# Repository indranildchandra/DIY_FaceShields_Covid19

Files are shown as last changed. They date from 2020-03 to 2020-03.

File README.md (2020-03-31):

# 10000 Face Shields For #COVID19 In India
* [Campaign page](https://www.ketto.org/donate-face-shields-to-covid-19-warriors-in-india?payment=form)

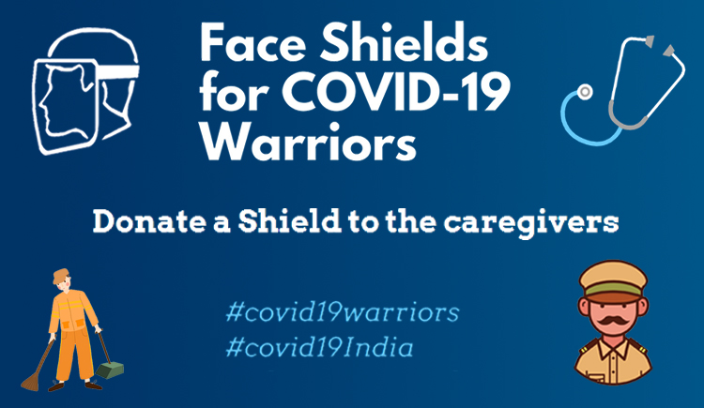
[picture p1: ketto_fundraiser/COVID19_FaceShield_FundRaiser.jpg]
Fundraiser


## Shield Images
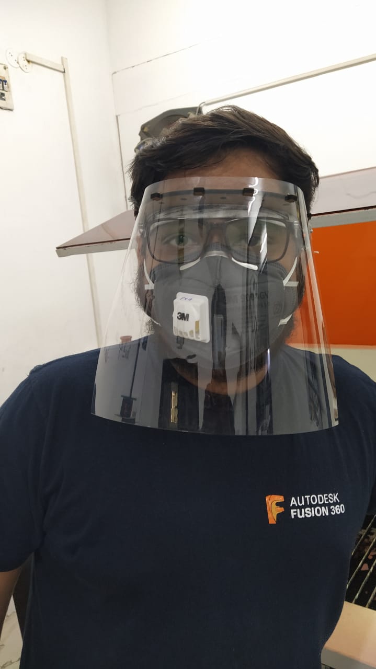
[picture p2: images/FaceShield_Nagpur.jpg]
Face Shield

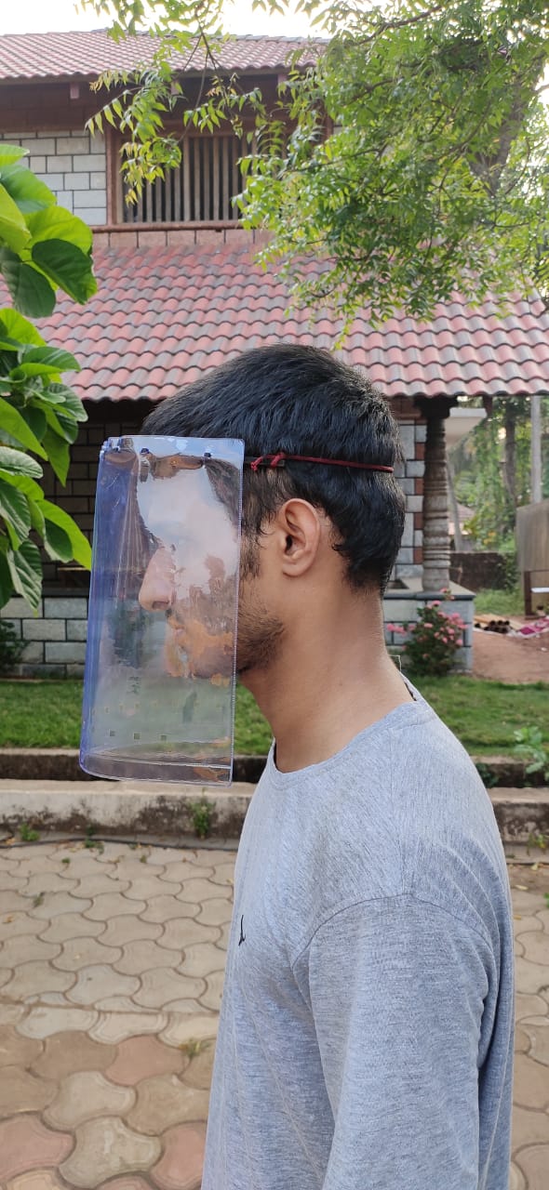
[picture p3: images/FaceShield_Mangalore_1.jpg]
Face Shield

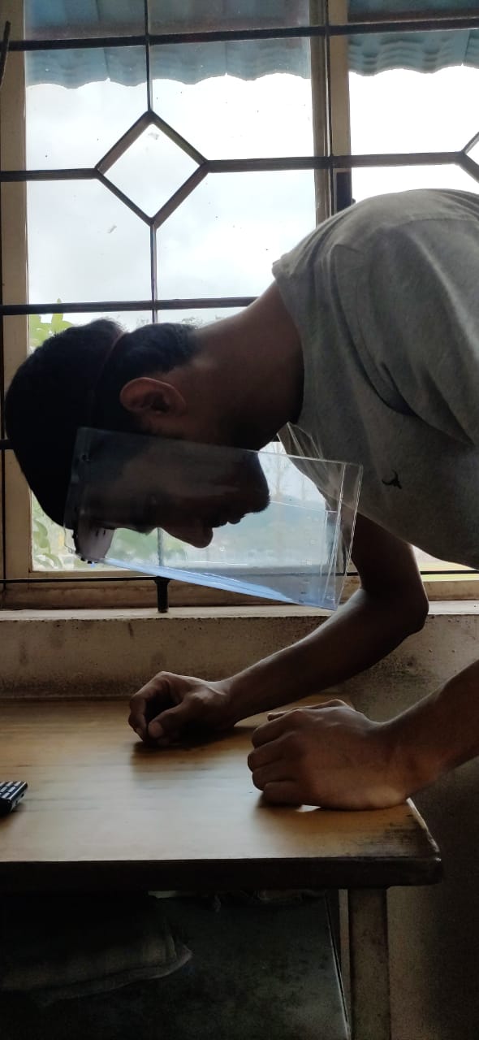
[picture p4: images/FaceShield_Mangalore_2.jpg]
Face Shield


## Design Credits
[Designs released by Makers Asylum Mumbai were re-used](https://github.com/MakersAsylumIndia/Covid-19)

License
-------
[CERN Open Hardware Licence Version 2 - Strongly Reciprocal]

[CERN Open Hardware Licence Version 2 - Strongly Reciprocal]:https://www.ohwr.org/project/cernohl/wikis/uploads/002d0b7d5066e6b3829168730237bddb/cern_ohl_s_v2.txt

[CERN OHL S v2 FAQ]: https://ohwr.org/project/cernohl/wikis/faq

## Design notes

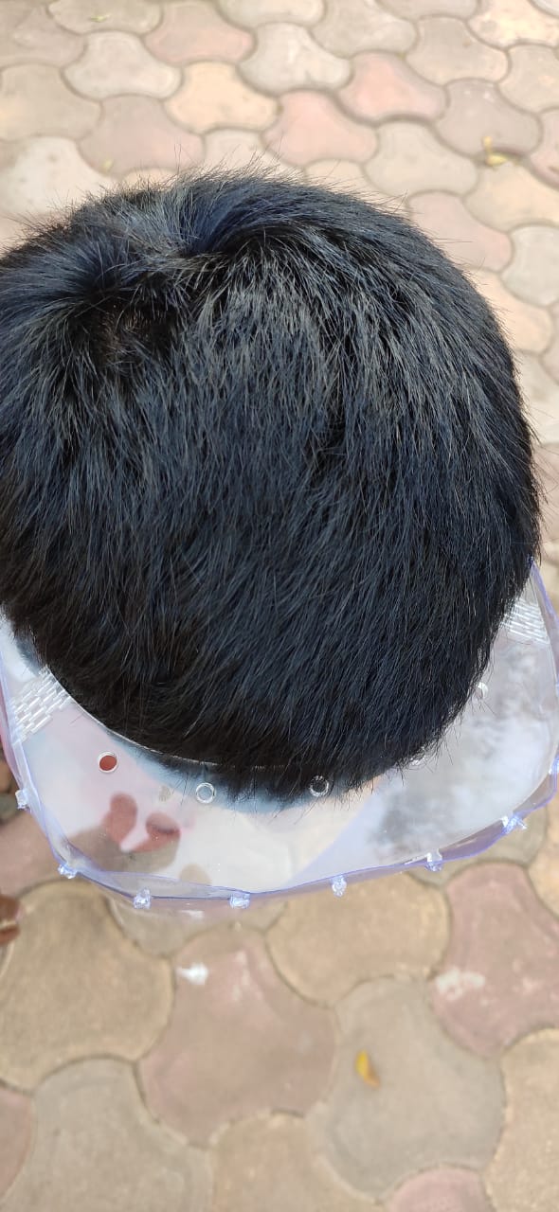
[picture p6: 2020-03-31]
images/FaceShield_Mangalore_4.jpg

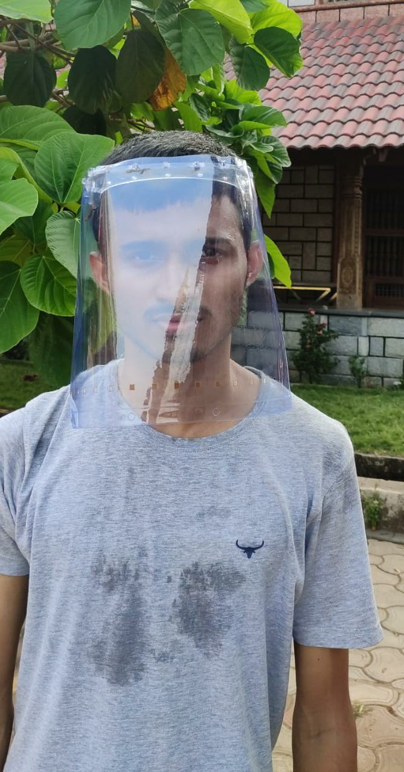
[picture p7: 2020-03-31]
images/FaceShield_Mangalore_3.jpg

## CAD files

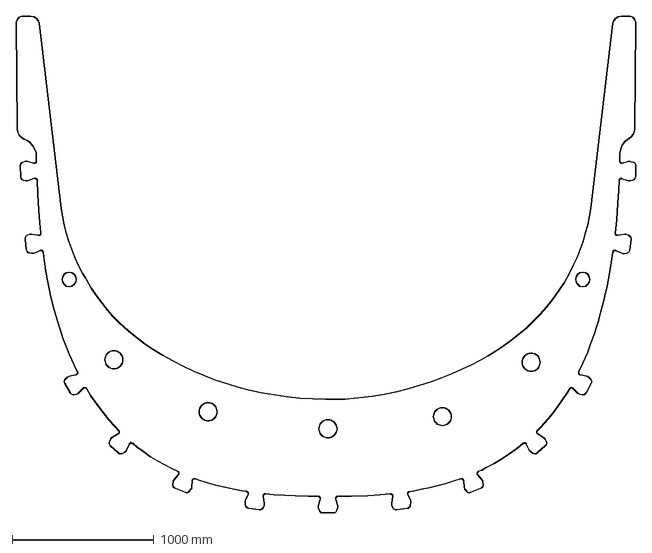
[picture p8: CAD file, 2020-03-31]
designs/face_shield_design.DXF
4367.9 x 3498.0 mm

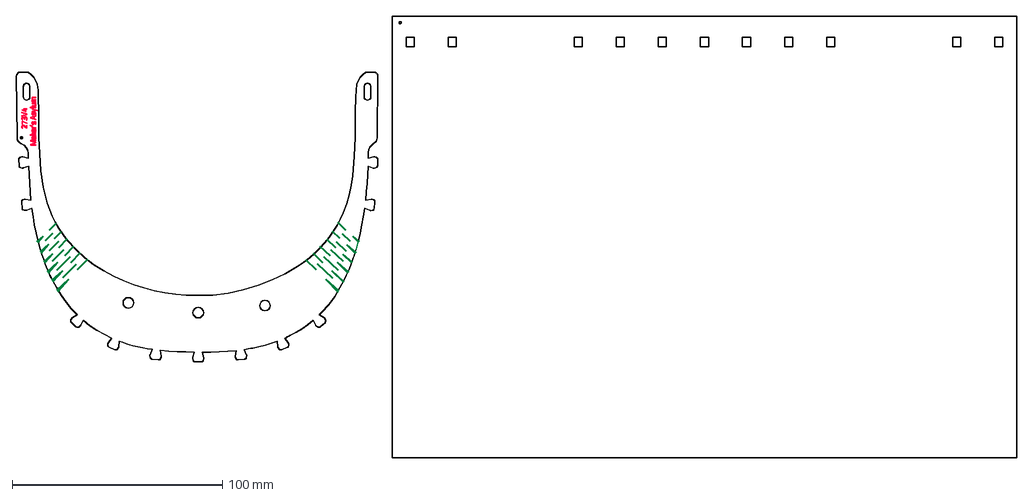
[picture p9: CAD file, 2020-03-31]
source_files_makers_asylum/Face_Shield_acrylic/acrylicShieldv5.dxf
475.8 x 210.0 mm

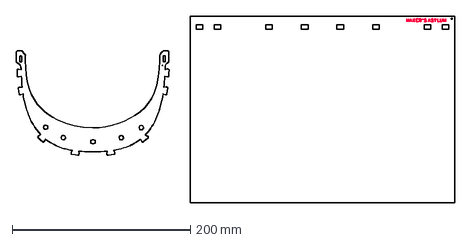
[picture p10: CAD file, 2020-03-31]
source_files_makers_asylum/Face_Shield_FoamBoard_Sun_Board/sunbaordshiledv6.dxf
492.4 x 210.0 mm

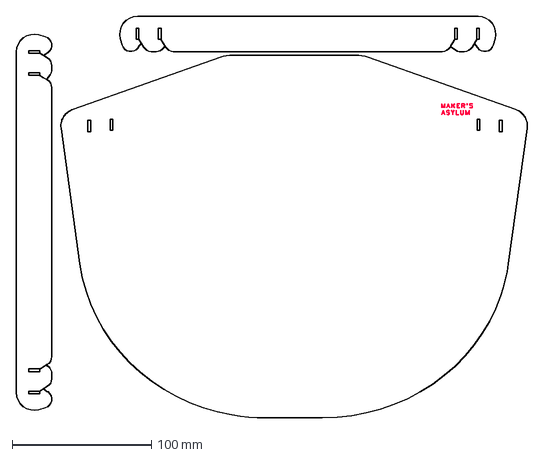
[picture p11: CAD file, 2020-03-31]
source_files_makers_asylum/Face_Shield_OHP_film/ohpShieldV7.dxf
367.0 x 288.4 mm

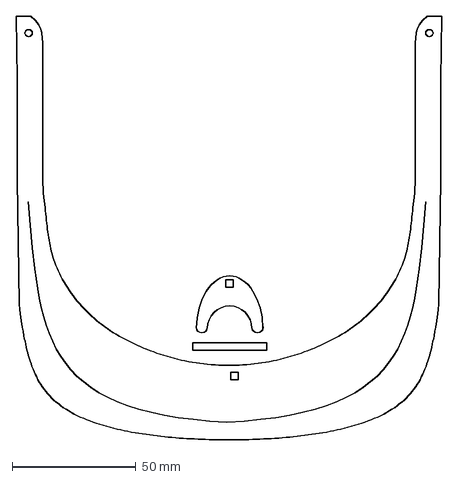
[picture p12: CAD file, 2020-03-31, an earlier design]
source_files_makers_asylum/old_versions/version1/shield.dxf
172.0 x 171.4 mm

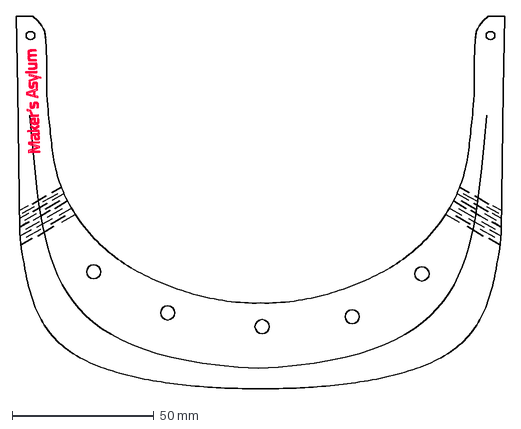
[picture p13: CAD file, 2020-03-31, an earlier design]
source_files_makers_asylum/old_versions/version2/shield-v2.dxf
172.0 x 131.2 mm

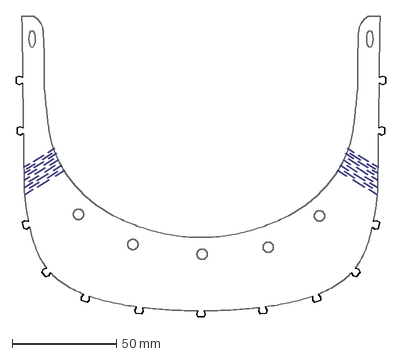
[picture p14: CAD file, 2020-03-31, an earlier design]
source_files_makers_asylum/old_versions/version3/sheildv3.dxf
177.2 x 144.5 mm

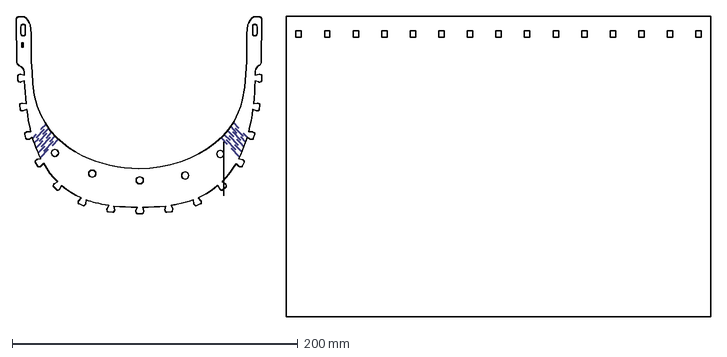
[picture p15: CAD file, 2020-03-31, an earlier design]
source_files_makers_asylum/old_versions/version4/Shieldv4.dxf
486.2 x 210.0 mm

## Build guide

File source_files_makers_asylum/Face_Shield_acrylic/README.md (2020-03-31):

# Face Shield ACRYLIC #

## BoM ##

1. HEAD BAND : Acrylic sheet, between 3mm to 5mm thick, (GREEN lines are living hinges, RED is Engraved Text)
2. SHIELD : OHP Transparency Film, A4 Size, 175 microns thick (100 microns works)
    If you need a longer shield, use A3 sheet, and trim length as needed
3. RETENTION : Elastic Band or similar for retention, approx. 200 mm / 8 inches long
4. OPTIONAL : Foam strip, adhesive. To be stuck on the inside surface that touches forehead, for long duration comfort (not essential)

## ASSEMBLY ##

1. Laser Cut the Acrylic head band.
2. Soak in Soap water for 30 minutes, and then in clean water for 30 minutes.
3. Air dry in the Sun.
4. Apply surgical plaster tape over the living hinges. This allows the band to be used if the living hinges break (Acrylic is brittle). We have used broken bands for over 8 hours at a stretch wthout problems. If you'd like to avoid this step altogether, take a look at the foam board design.
5. Attach the elastic retention band.
6. Apply foam along the area which comes in contact with the forehead. We used 2mm thick adhesive backed foam strips - about 10-15mm wide (approx 1/2 inch) and 200mm long (8 inches). This improves comfort over extended hours of use, but can be skipped, especially if the shield is already worn over other gear such as caps.
7. Snap fit the clear OHP film shields. If you're shipping these, you can pack the head bands and OHP films separately and the end user's can easily assemble before use.

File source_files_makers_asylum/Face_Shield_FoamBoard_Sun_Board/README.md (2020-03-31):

# Face Shield FOAM BOARD / SUN BOARD #

## BoM ##

1. HEAD BAND : Foam Board / Sun Board sheet, between 3mm to 5mm thick, (RED is Engraved Text)
2. SHIELD : OHP Transparency Film, A4 Size, 175 microns thick (100 microns works)
    If you need a longer shield, use A3 sheet, and trim length as needed
3. RETENTION : Elastic Band or similar for retention, approx. 200 mm / 8 inches long
4. OPTIONAL : Foam strip, adhesive. To be stuck on the inside surface that touches forehead, for long duration comfort (not essential)

## ASSEMBLY ##

1. Laser Cut the foam head band.
2. Laser Cut the OHP film (slots to fit the tabs in the head band)
3. Soak in Soap water for 30 minutes, and then in clean water for 30 minutes.
4. Air dry in the Sun.
5. Attach the elastic retention band.
6. Apply foam along the area which comes in contact with the forehead. We used 2mm thick adhesive backed foam strips - about 10-15mm wide (approx 1/2 inch) and 200mm long (8 inches). This improves comfort over extended hours of use, but can be skipped, especially if the shield is already worn over other gear such as caps.
7. Snap fit the clear OHP film shields. If you're shipping these, you can pack the head bands and OHP films separately and the end user's can easily assemble before use.
